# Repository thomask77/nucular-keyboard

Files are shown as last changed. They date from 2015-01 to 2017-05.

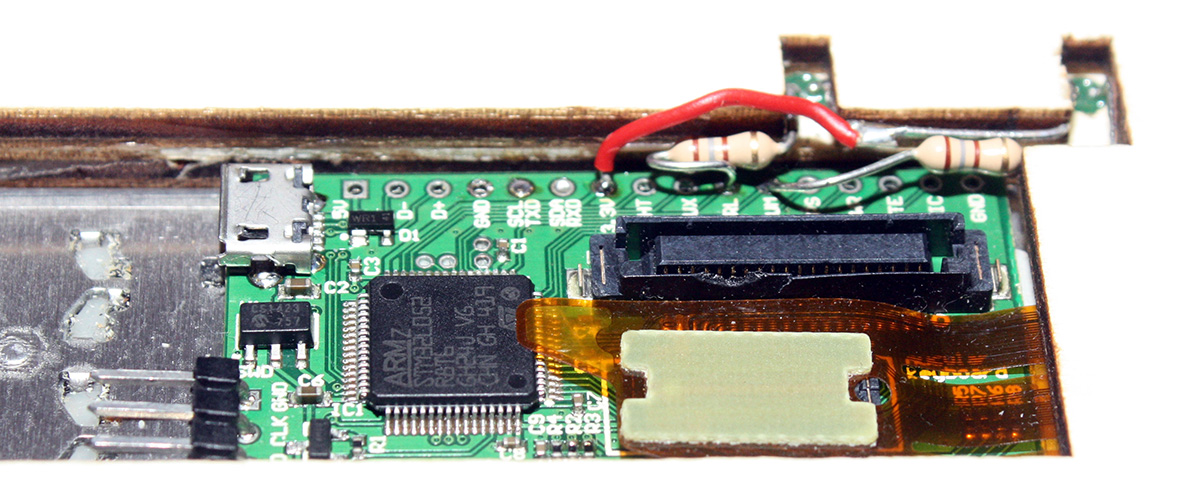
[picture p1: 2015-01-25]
Docs/IMG_5007.JPG

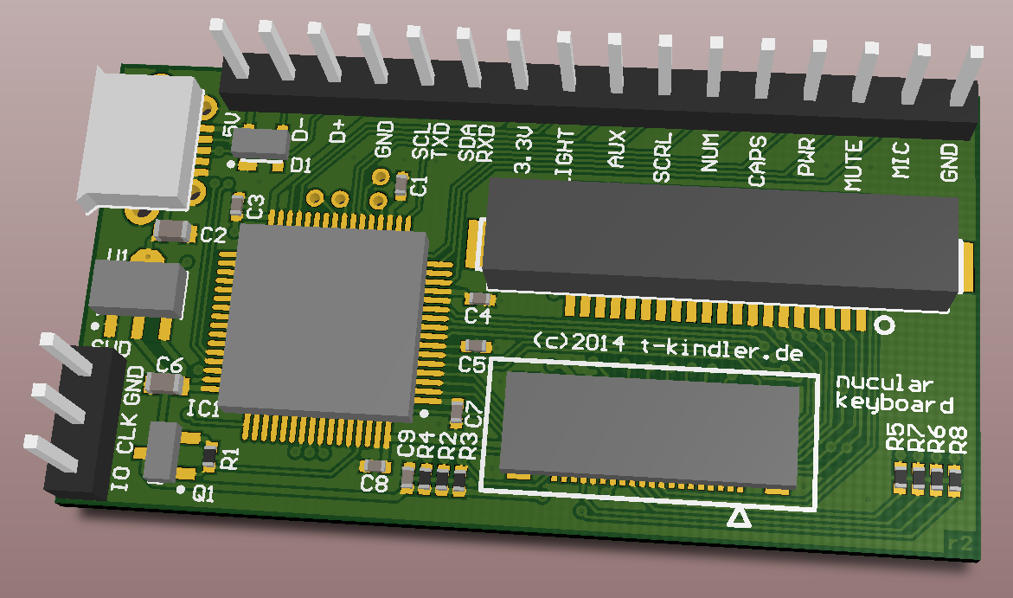
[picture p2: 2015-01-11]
Docs/nucular-keyboard.png

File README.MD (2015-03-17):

Toolchain
=========
  * gcc-arm-embedded toolchain >= 4.9-2014-q4
    * https://launchpad.net/gcc-arm-embedded

  * Other tools (use cygwin for windows)
    * python2
    * make

  * Initial flash programming
    * STM32 ST-LINK utility (windows)
    * https://github.com/texane/stlink (linux)

  * Flash programming with DFU bootloader
    * STM32 DfuSe utility (windows)
    * Openmoko dfu-util (linux)

Building
========
```bash
make boot    # Build USB DFU bootloader
make all     # Build actual keyboard application
```

Initial flash programming
=========================
Unfortunately, the STM32L052 does not have a built-in USB bootloader. So the
initial programming has to be done using a SWD adapter. A cheap STM32 discovery
board will do fine.

Windows
-------
Use the ST-LINK utility to flash `obj_boot/f00b00t.hex` and
`obj_app/nucular_kb.hex`.
   
Hint: You can also copy the ST-LINK utility to Tools/st-link and use `make`
to do the flashing:

```bash
make boot_flash
make flash
```

Linux
-----
Use Texane's stlink utility to do the flashing:

```bash
sudo st-flash --reset write obj_boot/f00b00t.bin 0x08000000
sudo st-flash --reset write obj_app/drquad.bin 0x08010000
```

Hint: Read the st-flash documentation and install udev rules
to flash without root privileges.

Flash programming with DFU bootloader
=====================================
After the USB DFU bootloader has been flashed, the application can be updated
without any external tools. Press FN+POWER on your keyboard to enter the DFU-
bootloader mode.

Windows
-------
Use ST's DfuSe Application to flash `obj_app/nucular_kb.dfu`

Linux
-----
Use Openmoko's dfu-util to flash the application:

```bash
sudo dfu-util -D obj_app/nucular_kb.dfu
```

printf()-Debugging
==================
The application uses a generic HID endpoint to print debug messages. This
endpoint is fully compatible with PJRC's [hid_listen] 
(https://www.pjrc.com/teensy/hid_listen.html) program.

The program (source and binaries) is included in the Tools directory.

Eclipse settings
================
  * Download and configure Eclipse Luna:
    * Help -> Install new Software -> Add
      * Name: `http://pydev.org/updates`
      * Location: `http://pydev.org/updates`
    * Install the following plugins:
      * Programming Languages
        * C/C++ Development Tools
      * Mobile and Device Development
        * C/C++ GCC Cross Compiler Support
        * C/C++ GDB Hardware Debugging
     * PyDev
        * PyDev for Eclipse
      * Collaboration
        * Eclipse Git Team Provider

  * Window -> Preferences
    * C/C++
      * Build -> Console -> Limit console output: `5000`
      * Editor -> Scalability -> .. number of lines: `50000`
      * Editor -> Folding -> Enable folding of preprocessor branches
      * Code Style -> Formatter -> Import: `Docs/Codestyle.xml`
      * Code Analysis -> Uncheck all options
    * General -> Editors -> Text Editors -> Spelling -> Disable spell checking

Import Project
--------------
  * File -> New -> Makefile Project with Existing Code
    -> Toolchain for Indexer Settigns: Cross GCC

  * Project -> Uncheck "Build Automatically" 
  
  * Project -> Properties -> C/C++ General
    * Preprocessor Include Paths, Macros, etc. -> Providers
      * CDT GCC Build Output Parser: `arm-none-eabi-gcc`
      * CDT Cross GCC Built-in Compiler Settings: `arm-none-eabi-gcc -E -P -v -dD "${INPUTS}"`

  * Make Target Window, Right Click -> New...
    * Target-name: `all -j8`
    * Target-name: `clean`

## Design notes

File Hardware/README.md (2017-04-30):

**KICAD BRANCH -- WORK IN PROGRESS**

**EXPECT FREQUENT REBASES**

# Hardware

# Software

  * KiCad nightly
  * FreeCAD v0.17_pre

# Credits
  * 3D Models for AA01B-S040VA1 and T60 Keyboard by Cong Nguyen, Licensed under
    [CC-BY](http://creativecommons.org/licenses/by/4.0/) License:
    * https://grabcad.com/library/aa01b-s040va1-model-1
    * https://grabcad.com/library/thinkpad-t60-keyboard-with-trackpoint-1

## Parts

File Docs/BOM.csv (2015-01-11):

Comment | Footprint | Quantity | Designator
100n | CAPC0402N | 7 | C1, C3, C4, C5, C7, C8, C9
10u | CAPC0603N | 2 | C2, C6
PRTR5V0U2X | SOT143B | 1 | D1
STM32L052 | TSQFP50P1200X1200X160-64N | 1 | IC1
JAE-KX14-KxD | JAE-KX14-K2D | 1 | J1
JAE-AA01B-S040VA1 | JAE-AA01B-S040VA1 | 1 | J2
HEADER 1x16 | HEADER 1x16 2.54MM | 1 | P1
IRLML6402 | SOT23_N | 1 | Q1
4k7 | RESC0402N | 4 | R1, R2, R3, R4
100R | RESC0402N | 4 | R5, R6, R7, R8
HEADER 1x3 | HEADER 1x3 2.54MM | 1 | SWD
MCP1700T-3302E/MB | SOT-89-MB3_N | 1 | U1
USB | USB_MICRO_FCI | 1 | USB1

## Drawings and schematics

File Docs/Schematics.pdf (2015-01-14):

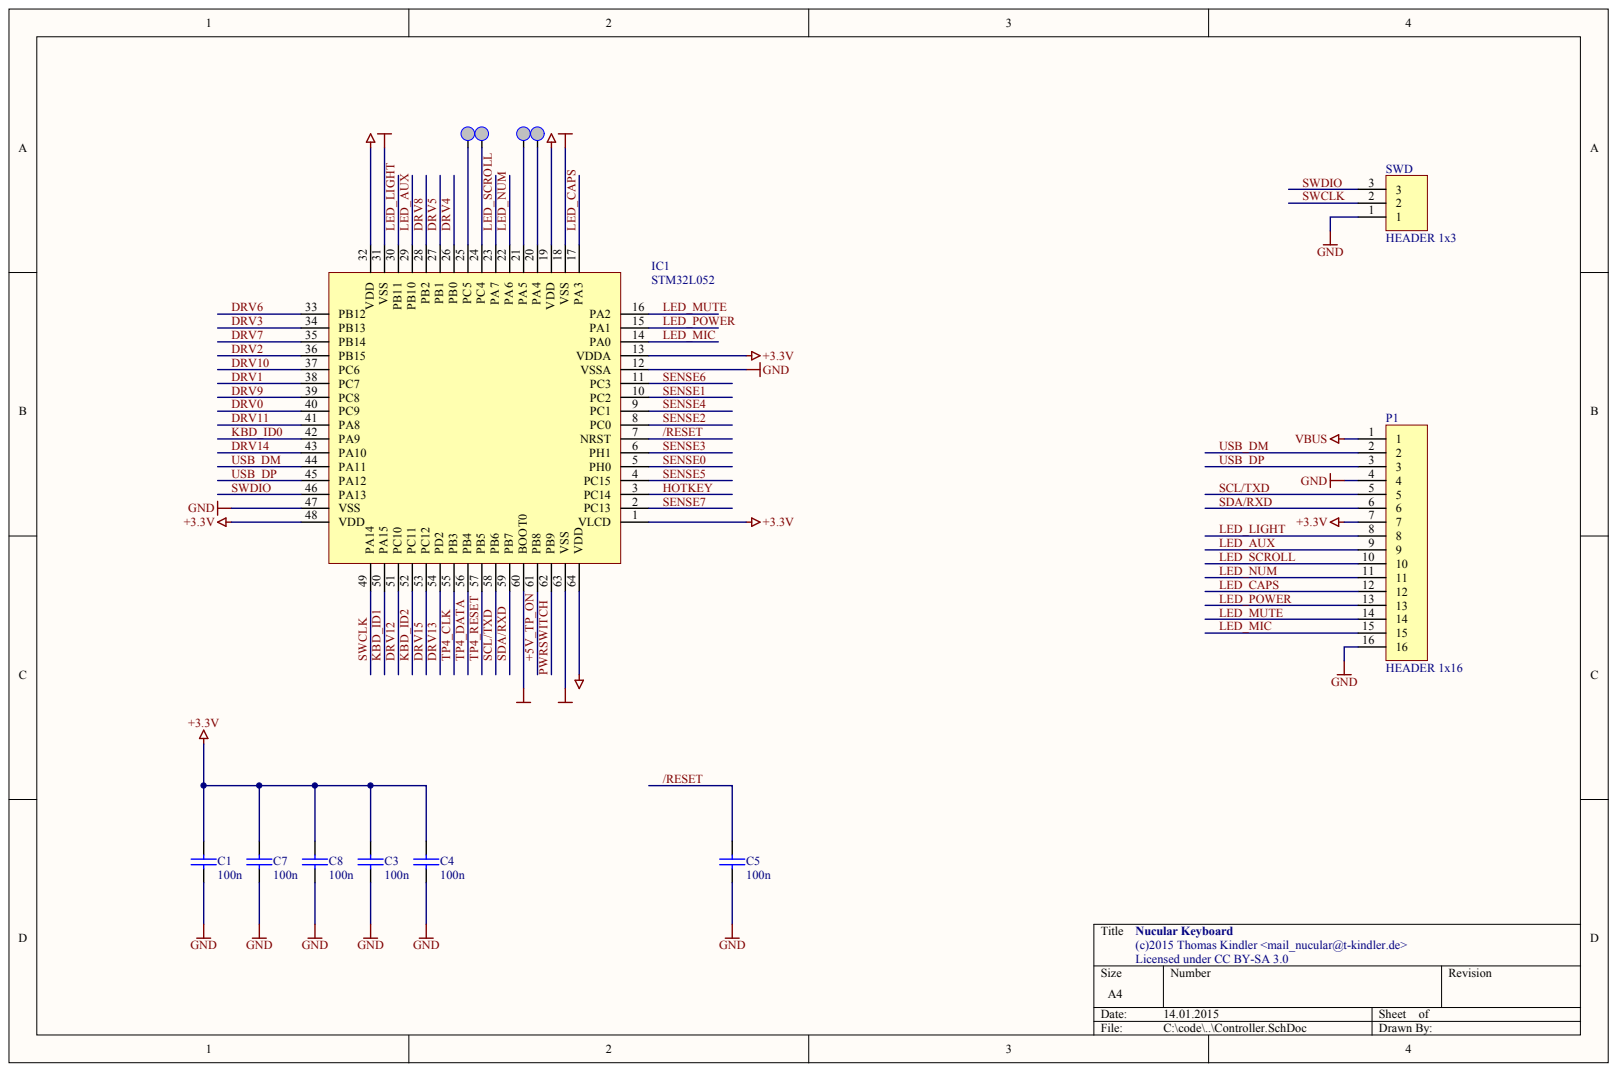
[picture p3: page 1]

PA3 17 VSS 18 VDD 19 PA4 20 PA5 21 PA6 22 PA7 23 PC4 24 PC5 25 PB0 26 PB1 27 PB2 28 PB10 29 PB11 30 VSS 31 VDD 32

SCL/TXD SDA/RXD

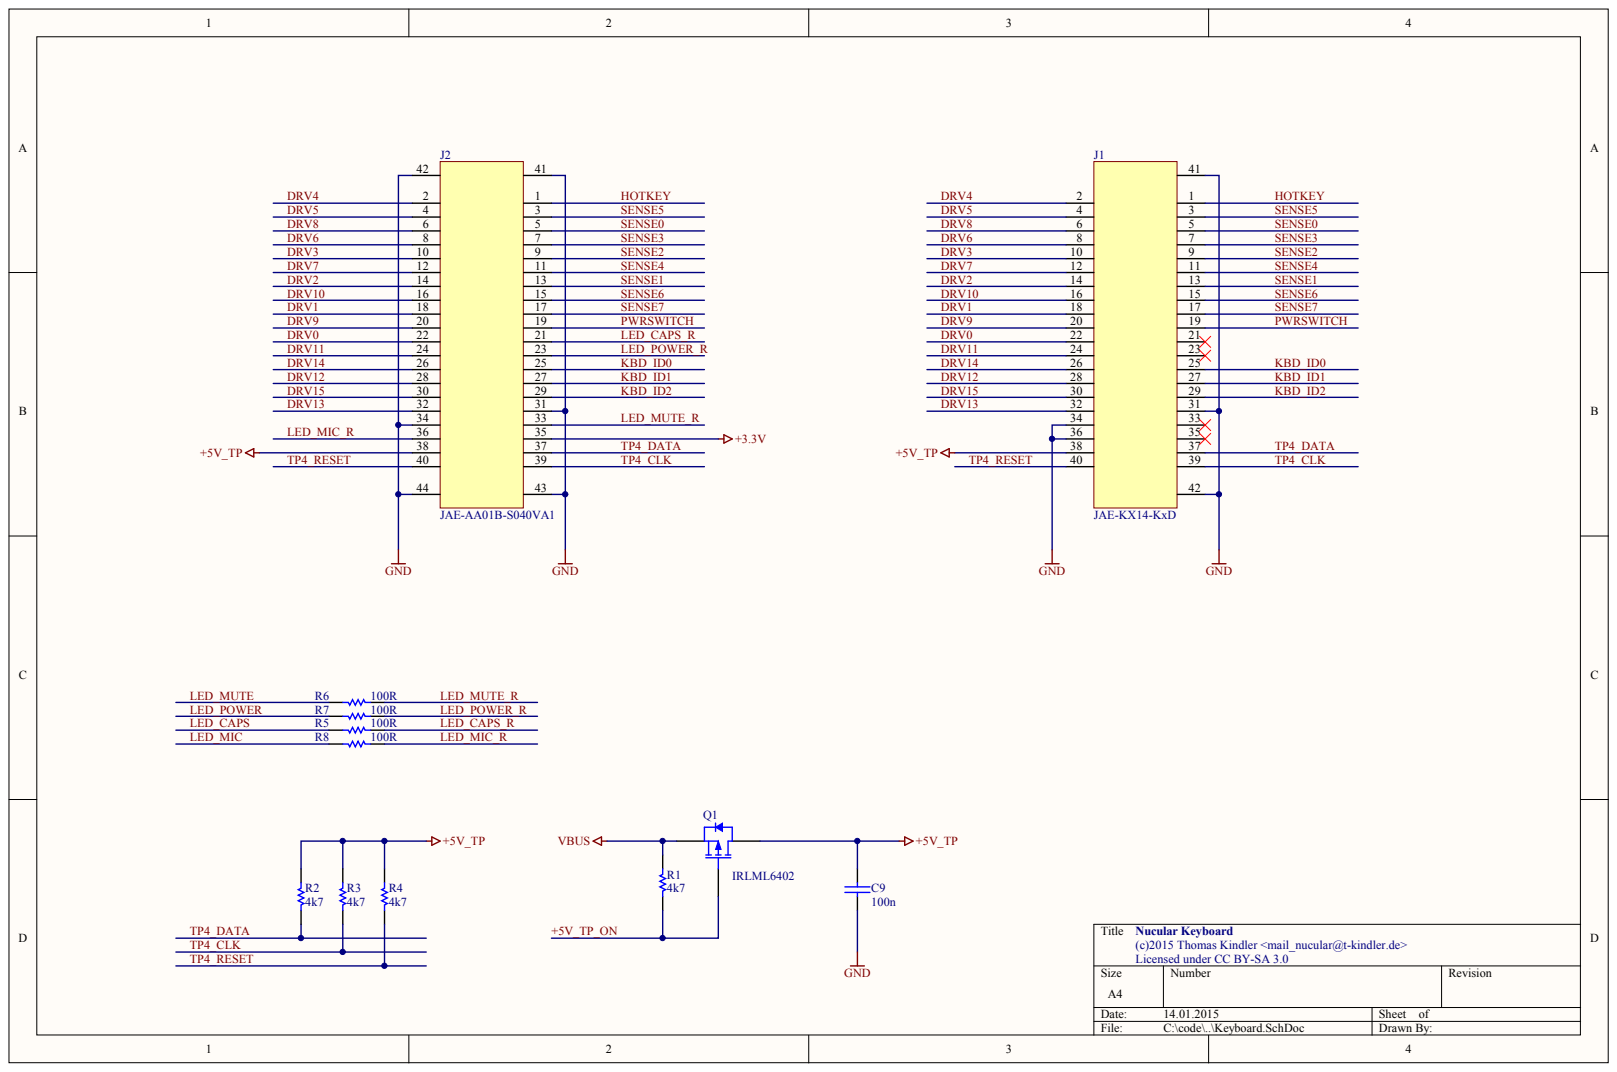
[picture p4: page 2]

2 4 6 8 10 12 14 16 18 20 22 24 26 28 30 32 34 | 1
3 | SENSE5
5 | SENSE0
7 | SENSE3
9 | SENSE2
11 | SENSE4
13 | SENSE1
15 | SENSE6
17 | SENSE7
19 | PWRSWITCH
21 | LED_CAPS_R
23 | LED_POWER_R
25 | KBD_ID0
27 | KBD_ID1
29 | KBD_ID2
31 | LED_MUTE_R
33

Nucular Keyboard
(c)2015 Thomas Kindler <mail_nucular@t-kindler.de>
Licensed under CC BY-SA 3.0

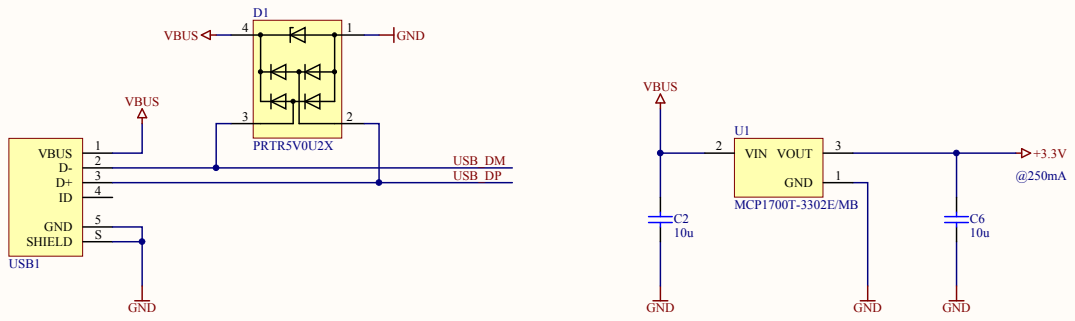
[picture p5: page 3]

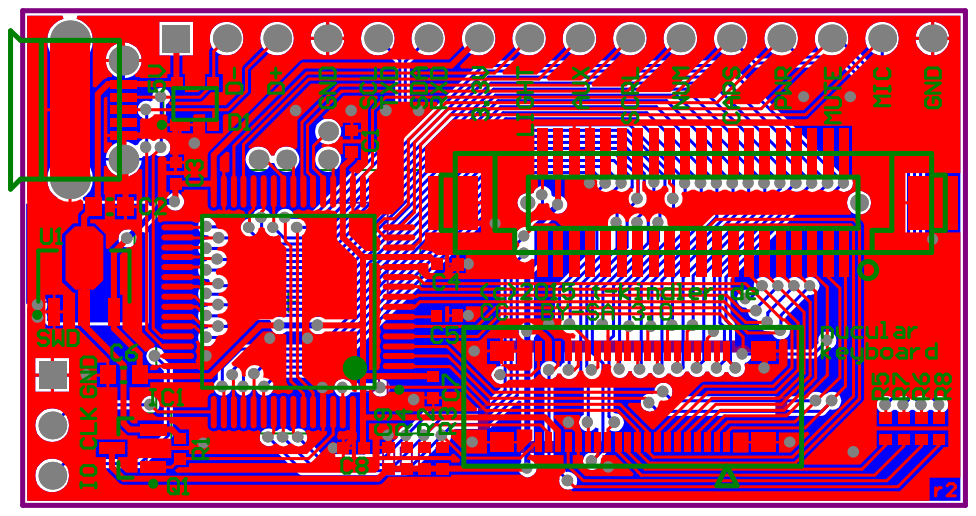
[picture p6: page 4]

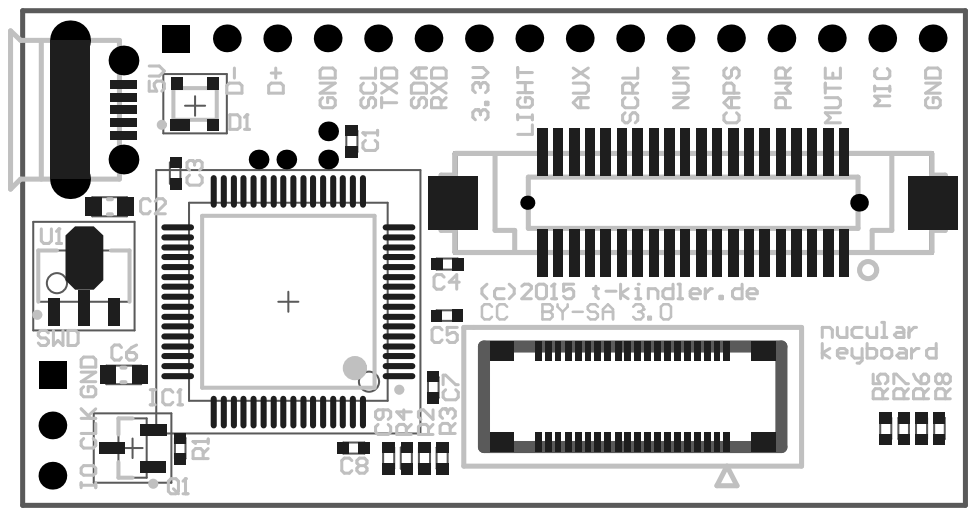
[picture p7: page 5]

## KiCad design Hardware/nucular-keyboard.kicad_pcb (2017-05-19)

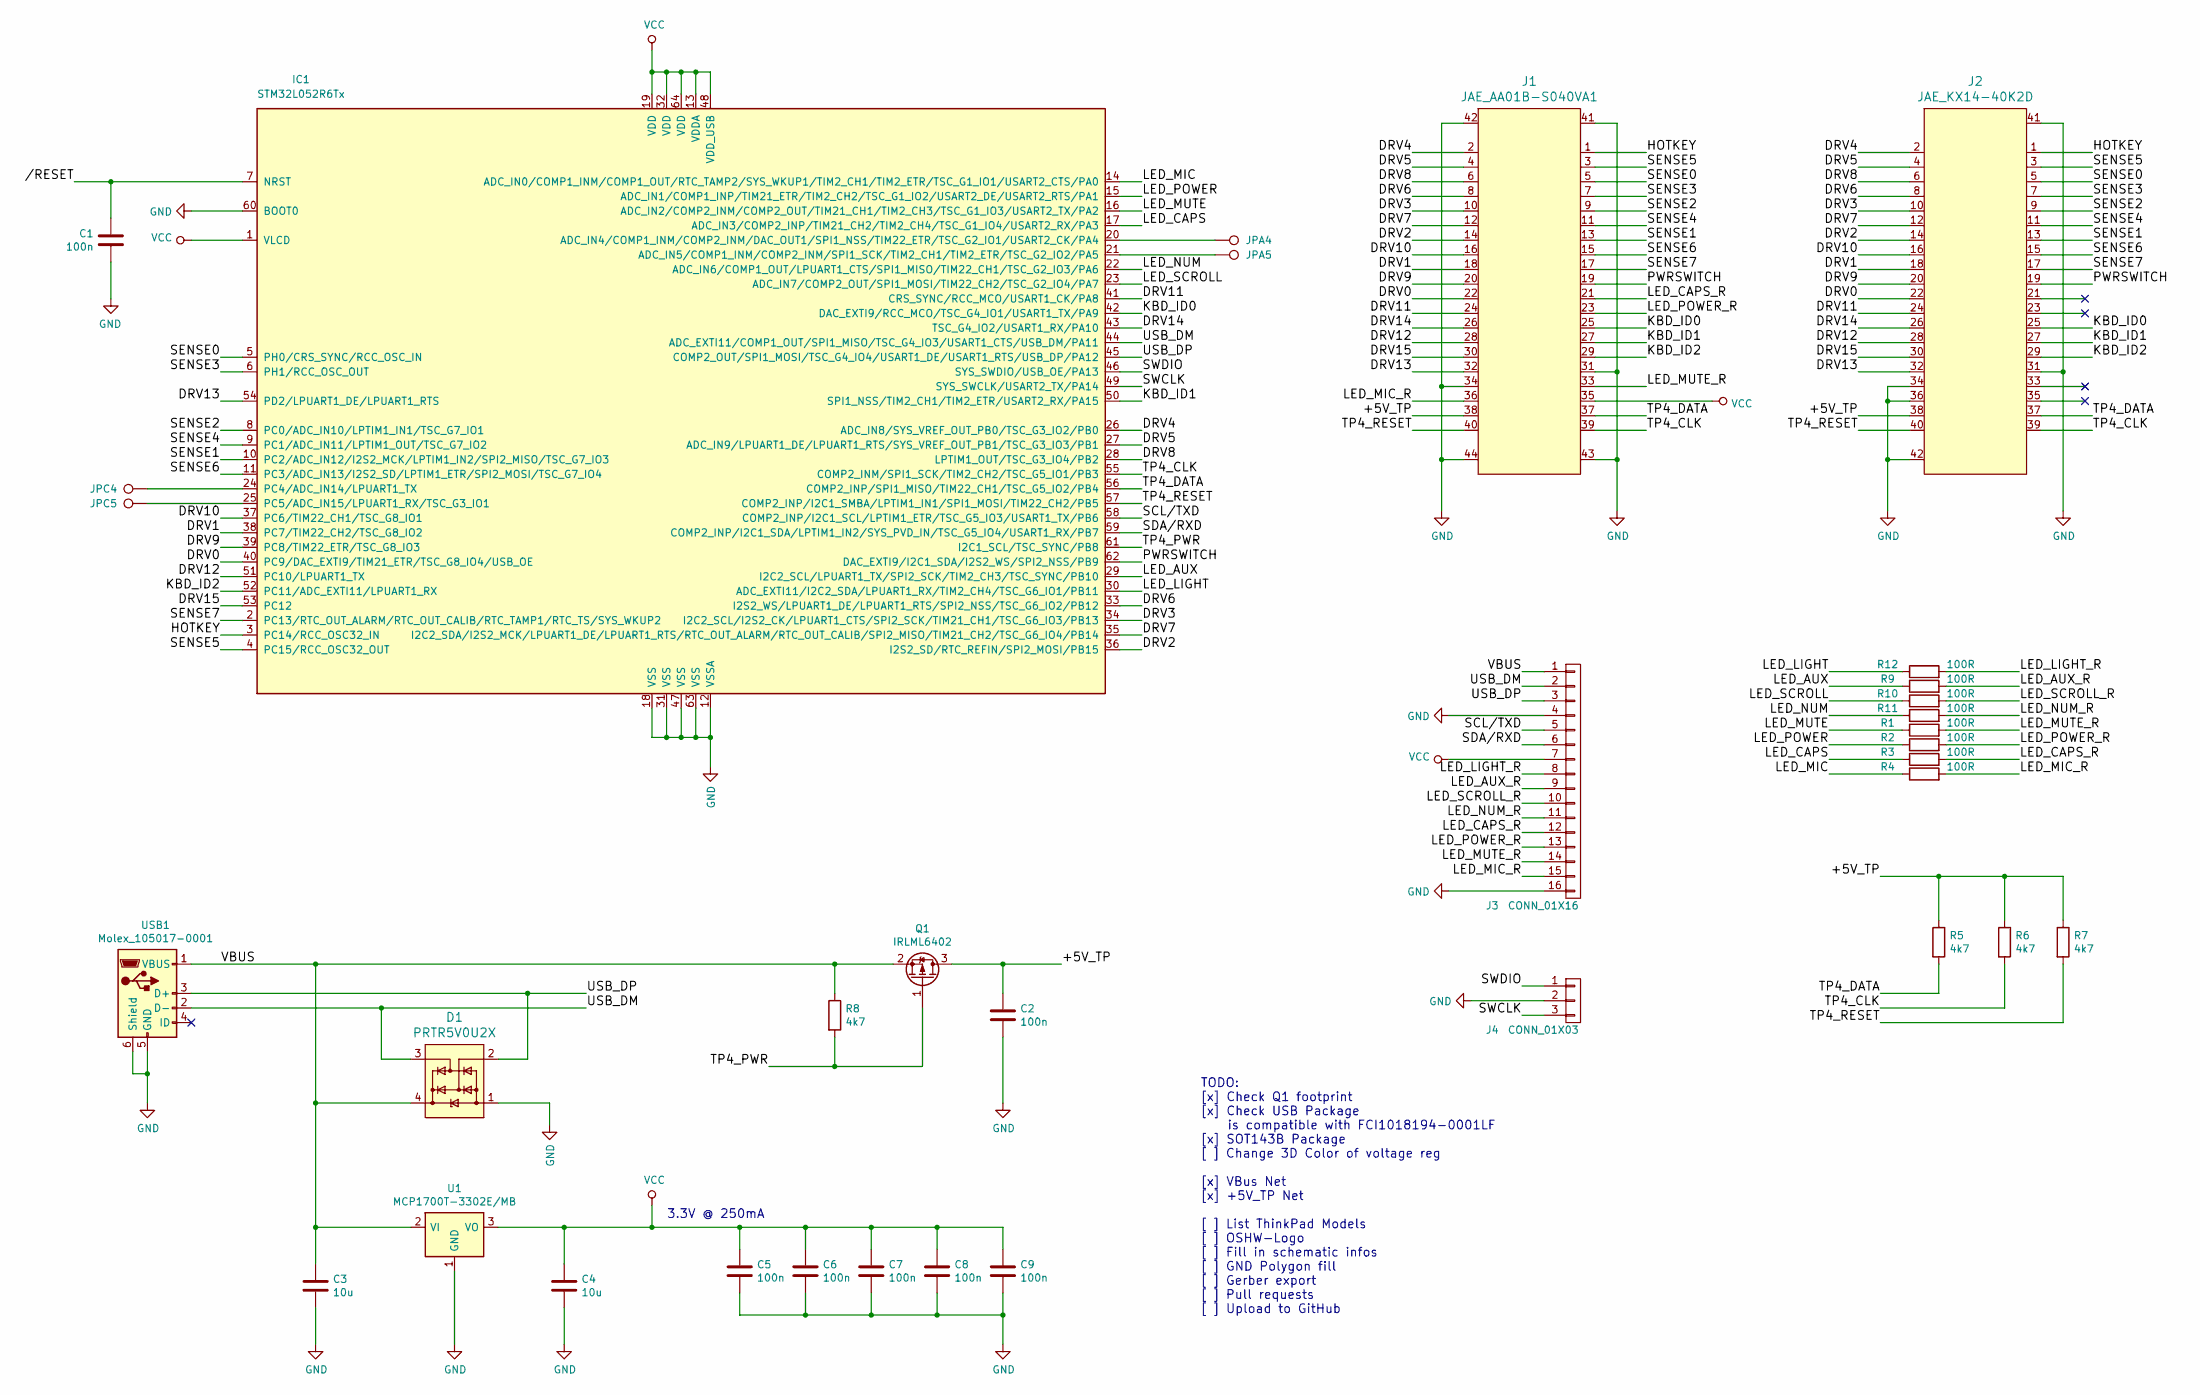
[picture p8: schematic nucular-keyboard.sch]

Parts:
C1, C2, C5, C6, C7, C8, C9: 100n; C_0402
C3, C4: 10u; C_0603
D1: PRTR5V0U2X; SOT143B
IC1: STM32L052R6Tx; LQFP-64_10x10mm_Pitch0.5mm
J1: JAE_AA01B-S040VA1
J2: JAE_KX14-40K2D
J3: CONN_01X16; Pin_Header_Straight_1x16_Pitch2.54mm
J4: CONN_01X03; Pin_Header_Straight_1x03_Pitch2.54mm
JPA4, JPA5: TEST_1P; SolderWirePad_single_0-8mmDrill
JPC4, JPC5: TEST_1P; SolderWirePad_single_0-8mmDrill
Q1: IRLML6402; SOT-23
R1, R2, R3, R4, R9, R10, R11, R12: 100R; R_0402
R5, R6, R7, R8: 4k7; R_0402
U1: MCP1700T-3302E/MB; SOT89-3
USB1: Molex_105017-0001; Molex_105017-0001_USB-Micro-B

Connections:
/+5V_TP: C2.1, J1.38, J2.38, Q1.3 (D), R5.1, R6.1, R7.1
//RESET: C1.1, IC1.7 (NRST)
/DRV0: IC1.40 (PC9/DAC_EXTI9/TIM21_ETR/TSC_G8_IO4/USB_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), J1.22, J2.22
/DRV1: IC1.38 (PC7/TIM22_CH2/TSC_G8_IO2), J1.18, J2.18
/DRV2: IC1.36 (I2S2_SD/RTC_REFIN/SPI2_MOSI/PB15), J1.14, J2.14
/DRV3: IC1.34 (I2C2_SCL/I2S2_CK/LPUART1_CTS/SPI2_SCK/T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), J1.10, J2.10
/DRV4: IC1.26 (ADC_IN8/SYS_VREF_OUT_PB0/TSC_G3_IO2/PB0), J1.2, J2.2
/DRV5: IC1.27 (ADC_IN9/LPUART1_DE/LPUART1_RTS/SYS_VREF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), J1.4, J2.4
/DRV6: IC1.33 (I2S2_WS/LPUART1_DE/LPUART1_RTS/SPI2_NSS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), J1.8, J2.8
/DRV7: IC1.35 (I2C2_SDA/I2S2_MCK/LPUART1_DE/LPUART1_RT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), J1.12, J2.12
/DRV8: IC1.28 (LPTIM1_OUT/TSC_G3_IO4/PB2), J1.6, J2.6
/DRV9: IC1.39 (PC8/TIM22_ETR/TSC_G8_IO3), J1.20, J2.20
/DRV10: IC1.37 (PC6/TIM22_CH1/TSC_G8_IO1), J1.16, J2.16
/DRV11: IC1.41 (CRS_SYNC/RCC_MCO/USART1_CK/PA8), J1.24, J2.24
/DRV12: IC1.51 (PC10/LPUART1_TX), J1.28, J2.28
/DRV13: IC1.54 (PD2/LPUART1_DE/LPUART1_RTS), J1.32, J2.32
/DRV14: IC1.43 (TSC_G4_IO2/USART1_RX/PA10), J1.26, J2.26
/DRV15: IC1.53 (PC12), J1.30, J2.30
/HOTKEY: IC1.3 (PC14/RCC_OSC32_IN), J1.1, J2.1
/KBD_ID0: IC1.42 (DAC_EXTI9/RCC_MCO/TSC_G4_IO1/USART1_TX/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), J1.25, J2.25
/KBD_ID1: IC1.50 (SPI1_NSS/TIM2_CH1/TIM2_ETR/USART2_RX/PA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), J1.27, J2.27
/KBD_ID2: IC1.52 (PC11/ADC_EXTI11/LPUART1_RX), J1.29, J2.29
/LED_AUX: IC1.29 (I2C2_SCL/LPUART1_TX/SPI2_SCK/TIM2_CH3/T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), R9.1
/LED_AUX_R: J3.9, R9.2
/LED_CAPS: IC1.17 (ADC_IN3/COMP2_INP/TIM21_CH2/TIM2_CH4/TS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), R3.1
/LED_CAPS_R: J1.21, J3.12, R3.2
/LED_LIGHT: IC1.30 (ADC_EXTI11/I2C2_SDA/LPUART1_RX/TIM2_CH4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), R12.1
/LED_LIGHT_R: J3.8, R12.2
/LED_MIC: IC1.14 (ADC_IN0/COMP1_INM/COMP1_OUT/RTC_TAMP2/S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), R4.1
/LED_MIC_R: J1.36, J3.15, R4.2
/LED_MUTE: IC1.16 (ADC_IN2/COMP2_INM/COMP2_OUT/TIM21_CH1/T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), R1.1
/LED_MUTE_R: J1.33, J3.14, R1.2
/LED_NUM: IC1.22 (ADC_IN6/COMP1_OUT/LPUART1_CTS/SPI1_MISO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), R11.1
/LED_NUM_R: J3.11, R11.2
/LED_POWER: IC1.15 (ADC_IN1/COMP1_INP/TIM21_ETR/TIM2_CH2/TS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), R2.1
/LED_POWER_R: J1.23, J3.13, R2.2
/LED_SCROLL: IC1.23 (ADC_IN7/COMP2_OUT/SPI1_MOSI/TIM22_CH2/T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), R10.1
/LED_SCROLL_R: J3.10, R10.2
/PWRSWITCH: IC1.62 (DAC_EXTI9/I2C1_SDA/I2S2_WS/SPI2_NSS/PB9), J1.19, J2.19
/SCL/TXD: IC1.58 (COMP2_INP/I2C1_SCL/LPTIM1_ETR/TSC_G5_IO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), J3.5
/SDA/RXD: IC1.59 (COMP2_INP/I2C1_SDA/LPTIM1_IN2/SYS_PVD_I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), J3.6
/SENSE0: IC1.5 (PH0/CRS_SYNC/RCC_OSC_IN), J1.5, J2.5
/SENSE1: IC1.10 (PC2/ADC_IN12/I2S2_MCK/LPTIM1_IN2/SPI2_M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), J1.13, J2.13
/SENSE2: IC1.8 (PC0/ADC_IN10/LPTIM1_IN1/TSC_G7_IO1), J1.9, J2.9
/SENSE3: IC1.6 (PH1/RCC_OSC_OUT), J1.7, J2.7
/SENSE4: IC1.9 (PC1/ADC_IN11/LPTIM1_OUT/TSC_G7_IO2), J1.11, J2.11
/SENSE5: IC1.4 (PC15/RCC_OSC32_OUT), J1.3, J2.3
/SENSE6: IC1.11 (PC3/ADC_IN13/I2S2_SD/LPTIM1_ETR/SPI2_MO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), J1.15, J2.15
/SENSE7: IC1.2 (PC13/RTC_OUT_ALARM/RTC_OUT_CALIB/RTC_TA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), J1.17, J2.17
/SWCLK: IC1.49 (SYS_SWCLK/USART2_TX/PA14), J4.3
/SWDIO: IC1.46 (SYS_SWDIO/USB_OE/PA13), J4.1
/TP4_CLK: IC1.55 (COMP2_INM/SPI1_SCK/TIM2_CH2/TSC_G5_IO1/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), J1.39, J2.39, R6.2
/TP4_DATA: IC1.56 (COMP2_INP/SPI1_MISO/TIM22_CH1/TSC_G5_IO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), J1.37, J2.37, R5.2
/TP4_PWR: IC1.61 (I2C1_SCL/TSC_SYNC/PB8), Q1.1 (G), R8.2
/TP4_RESET: IC1.57 (COMP2_INP/I2C1_SMBA/LPTIM1_IN1/SPI1_MOS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), J1.40, J2.40, R7.2
/USB_DM: D1.3 (DM), IC1.44 (ADC_EXTI11/COMP1_OUT/SPI1_MISO/TSC_G4_I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), J3.2, USB1.2 (D-)
/USB_DP: D1.2 (DP), IC1.45 (COMP2_OUT/SPI1_MOSI/TSC_G4_IO4/USART1_D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), J3.3, USB1.3 (D+)
/VBUS: C3.1, D1.4 (VBUS), J3.1, Q1.2 (S), R8.1, U1.2 (VI), USB1.1 (VBUS)
GND: C1.2, C2.2, C3.2, C4.2, C5.2, C6.2, C7.2, C8.2, C9.2, D1.1 (GND), IC1.12 (VSSA), IC1.18 (VSS), IC1.31 (VSS), IC1.47 (VSS), IC1.60 (BOOT0), IC1.63 (VSS), J1.31, J1.34, J1.41, J1.42, J1.43, J1.44, J2.31, J2.34, J2.36, J2.41, J2.42, J3.4, J3.16, J4.2, U1.1 (GND), USB1.5 (GND), USB1.6 (Shield)
unnamed: IC1.20 (ADC_IN4/COMP1_INM/COMP2_INM/DAC_OUT1/SP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), JPA4.1
unnamed: IC1.21 (ADC_IN5/COMP1_INM/COMP2_INM/SPI1_SCK/TI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), JPA5.1
unnamed: IC1.24 (PC4/ADC_IN14/LPUART1_TX), JPC4.1
unnamed: IC1.25 (PC5/ADC_IN15/LPUART1_RX/TSC_G3_IO1), JPC5.1
VCC: C4.1, C5.1, C6.1, C7.1, C8.1, C9.1, IC1.1 (VLCD), IC1.13 (VDDA), IC1.19 (VDD), IC1.32 (VDD), IC1.48 (VDD_USB), IC1.64 (VDD), J1.35, J3.7, U1.3 (VO)

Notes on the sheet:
3.3V @ 250mA
TODO: [x] Check Q1 footprint [x] Check USB Package is compatible with FCI1018194-0001LF [x] SOT143B Package [ ] Change 3D Color of voltage reg [x] VBus Net [x] +5V_TP Net [ ] List ThinkPad Models [ ] OSHW-Logo [ ] Fill in schematic infos [ ] GND Polygon fill [ ] Gerber export [ ] Pull requests [ ] 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

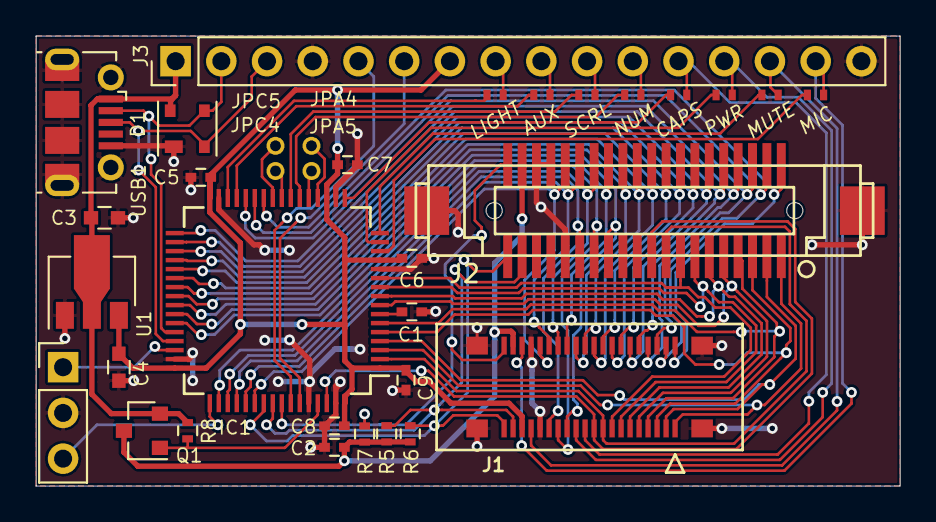
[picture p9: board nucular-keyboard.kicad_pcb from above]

Board: 2 copper layers, 48.0 x 25.0 mm, 34 parts (0 on the bottom side), 64 nets.

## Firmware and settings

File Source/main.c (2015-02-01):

/**
 * Nucular Keyboard - ThinkPad USB Adapter
 * Copyright (C)2015 Thomas Kindler <mail_nucular@t-kindler.de>
 *
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
 * You should have received a copy of the GNU General Public License
 * along with this program.  If not, see <http://www.gnu.org/licenses/>.
 */
#include "hid_debug.h"
#include "kb_driver.h"
#include "keyboard.h"
#include "ps2_host.h"
#include "trackpoint.h"
#include "ustime.h"
#include "ansi.h"
#include "usbd_desc.h"
#include "usbd_hid.h"
#include "stm32l0xx.h"


static IWDG_HandleTypeDef hiwdg;
USBD_HandleTypeDef hUsbDeviceFS;
extern PCD_HandleTypeDef hpcd_USB_FS;


void USB_IRQHandler(void)
{
    HAL_NVIC_ClearPendingIRQ(USB_IRQn);
    HAL_PCD_IRQHandler(&hpcd_USB_FS);
}


void SysTick_Handler(void)
{
    HAL_IncTick();
    HAL_SYSTICK_IRQHandler();
}


void SystemClock_Config(void)
{
    RCC_CRSInitTypeDef RCC_CRSInitStruct;
    RCC_ClkInitTypeDef RCC_ClkInitStruct;
    RCC_PeriphCLKInitTypeDef PeriphClkInit;
    RCC_OscInitTypeDef RCC_OscInitStruct;

    __PWR_CLK_ENABLE();

    __HAL_PWR_VOLTAGESCALING_CONFIG(PWR_REGULATOR_VOLTAGE_SCALE1);

    RCC_OscInitStruct.OscillatorType = RCC_OSCILLATORTYPE_HSI | RCC_OSCILLATORTYPE_LSI | RCC_OSCILLATORTYPE_HSI48;
    RCC_OscInitStruct.HSIState = RCC_HSI_ON;
    RCC_OscInitStruct.HSICalibrationValue = 16;
    RCC_OscInitStruct.LSIState = RCC_LSI_ON;
    RCC_OscInitStruct.HSI48State = RCC_HSI48_ON;
    RCC_OscInitStruct.PLL.PLLState = RCC_PLL_ON;
    RCC_OscInitStruct.PLL.PLLSource = RCC_PLLSOURCE_HSI;
    RCC_OscInitStruct.PLL.PLLMUL = RCC_PLLMUL_4;
    RCC_OscInitStruct.PLL.PLLDIV = RCC_PLLDIV_2;
    HAL_RCC_OscConfig(&RCC_OscInitStruct);

    RCC_ClkInitStruct.ClockType = RCC_CLOCKTYPE_SYSCLK;
    RCC_ClkInitStruct.SYSCLKSource = RCC_SYSCLKSOURCE_PLLCLK;
    RCC_ClkInitStruct.AHBCLKDivider = RCC_SYSCLK_DIV1;
    RCC_ClkInitStruct.APB1CLKDivider = RCC_HCLK_DIV1;
    RCC_ClkInitStruct.APB2CLKDivider = RCC_HCLK_DIV1;
    HAL_RCC_ClockConfig(&RCC_ClkInitStruct, FLASH_LATENCY_1);

    PeriphClkInit.PeriphClockSelection = RCC_PERIPHCLK_USART1 | RCC_PERIPHCLK_USB;
    PeriphClkInit.Usart1ClockSelection = RCC_USART1CLKSOURCE_PCLK2;
    PeriphClkInit.UsbClockSelection = RCC_USBCLKSOURCE_HSI48;
    HAL_RCCEx_PeriphCLKConfig(&PeriphClkInit);

    __SYSCFG_CLK_ENABLE();

    __CRS_CLK_ENABLE();

    RCC_CRSInitStruct.Prescaler = RCC_CRS_SYNC_DIV1;
    RCC_CRSInitStruct.Source = RCC_CRS_SYNC_SOURCE_USB;
    RCC_CRSInitStruct.Polarity = RCC_CRS_SYNC_POLARITY_RISING;
    RCC_CRSInitStruct.ReloadValue = __HAL_RCC_CRS_CALCULATE_RELOADVALUE(48000000, 1000);
    RCC_CRSInitStruct.ErrorLimitValue = 34;
    RCC_CRSInitStruct.HSI48CalibrationValue = 32;
    HAL_RCCEx_CRSConfig(&RCC_CRSInitStruct);
}


static void MX_IWDG_Init(void)
{
    hiwdg.Instance = IWDG;
    hiwdg.Init.Prescaler = IWDG_PRESCALER_4;
    hiwdg.Init.Reload = 50;
    HAL_IWDG_Init(&hiwdg);
}


void MX_GPIO_Init(void)
{
    /* GPIO Ports Clock Enable */
    __GPIOA_CLK_ENABLE();
    __GPIOB_CLK_ENABLE();
    __GPIOC_CLK_ENABLE();
    __GPIOD_CLK_ENABLE();
}


void MX_USB_DEVICE_Init(void)
{
    USBD_Init(&hUsbDeviceFS, &FS_Desc, DEVICE_FS);
    USBD_RegisterClass(&hUsbDeviceFS, &USBD_HID);
    USBD_Start(&hUsbDeviceFS);
}


void assert_failed(uint8_t* file, uint32_t line)
{
    printf("assert failed: %s:%lu\n", file, line);
}


void handle_out_requests(void)
{
    USBD_HID_HandleTypeDef *hhid = hUsbDeviceFS.pClassData;

    if (!hhid->ep0_out_req_ready)
        return;

    uint8_t report_type = hhid->ep0_out_req.wValue >> 8;
    uint8_t report_id = hhid->ep0_out_req.wValue & 0xff;

    switch (hhid->ep0_out_req.wIndex) {
    case 0:
        if (report_type == 2 && report_id == 0)
            kb_set_leds((struct kb_out_report *)hhid->ep0_out_buf);
        break;

    case 2:
        if (report_type == 3 && report_id == 0x80)
            enter_bootloader();
        break;
    }

    hhid->ep0_out_req_ready = 0;
}


int main(void)
{
    SCB->VTOR = 0x8004000;  // Relocate IRQ table

    HAL_Init();
    SystemClock_Config();
    HAL_NVIC_SetPriority(SysTick_IRQn, 0, 0);

    MX_GPIO_Init();
    // MX_IWDG_Init();
    MX_USB_DEVICE_Init();

    // PA4  Debug output
    // PA5  Debug output
    //
    HAL_GPIO_Init(GPIOA, &(GPIO_InitTypeDef) {
        .Pin   = GPIO_PIN_4 | GPIO_PIN_5,
        .Mode  = GPIO_MODE_OUTPUT_PP,
        .Pull  = GPIO_PULLUP,
        .Speed = GPIO_SPEED_LOW
    } );

    init_us_timer();

    printf("Initializing keyboard interface..\n");
    kb_init();

    printf("Initializing TrackPoint interface..\n");
    tp_init();

    static struct tp_mouse_report     mr_old;
    static struct kb_in_report        kr_old;
    static struct kb_sysctrl_report   sr_old;
    static struct kb_consumer_report  cr_old;

    for (;;) {
        kb_update();
        tp_update();

        // Send keyboard reports on state change only
        //
        if (memcmp(&kb_in_report, &kr_old, sizeof(kb_in_report))) {
            if (USBD_HID_SendReport(&hUsbDeviceFS, HID_KEYBOARD_EPIN_ADDR, &kb_in_report, sizeof(kb_in_report)) == USBD_OK)
                kr_old = kb_in_report;
        }

        if (memcmp(&kb_sysctrl_report, &sr_old, sizeof(kb_sysctrl_report))) {
            if (USBD_HID_SendReport(&hUsbDeviceFS, HID_EXTRA_EPIN_ADDR, &kb_sysctrl_report, sizeof(kb_sysctrl_report)) == USBD_OK)
                sr_old = kb_sysctrl_report;
        }

        if (memcmp(&kb_consumer_report, &cr_old, sizeof(kb_consumer_report))) {
            if (USBD_HID_SendReport(&hUsbDeviceFS, HID_EXTRA_EPIN_ADDR, &kb_consumer_report, sizeof(kb_consumer_report)) == USBD_OK)
                cr_old = kb_consumer_report;
        }

        // Send mouse reports while moving and on button change
        //
        if (tp_mouse_report.dx      || tp_mouse_report.dy   ||
            tp_mouse_report.dwheel  || tp_mouse_report.dpan ||
            tp_mouse_report.buttons != mr_old.buttons)
        {
            if (USBD_HID_SendReport(&hUsbDeviceFS, HID_MOUSE_EPIN_ADDR, &tp_mouse_report, sizeof(tp_mouse_report)) == USBD_OK) {
                tp_clear_mouse_report();
                mr_old = tp_mouse_report;
            }
        }

        hid_debug_flush();

        handle_out_requests();
    }
}

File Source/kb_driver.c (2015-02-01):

/**
 * Nucular Keyboard - Low-level keyboard driver
 * Copyright (C)2015 Thomas Kindler <mail_nucular@t-kindler.de>
 *
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
 * You should have received a copy of the GNU General Public License
 * along with this program.  If not, see <http://www.gnu.org/licenses/>.
 */
#include "kb_driver.h"
#include "ustime.h"
#include "util.h"
#include "gamma_tab.inc"
#include "stm32l0xx_hal.h"
#include <stdio.h>


// If you ever change the pinout, print this stuff out and tick it off with a pencil..
//
#define GPIOA_DRV_BITS      (GPIO_PIN_8  | GPIO_PIN_10)
#define GPIOB_DRV_BITS      (GPIO_PIN_0  | GPIO_PIN_1 | GPIO_PIN_2 | GPIO_PIN_12 | GPIO_PIN_13 | GPIO_PIN_14 | GPIO_PIN_15)
#define GPIOC_DRV_BITS      (GPIO_PIN_6  | GPIO_PIN_7 | GPIO_PIN_8 | GPIO_PIN_9  | GPIO_PIN_10 | GPIO_PIN_12)
#define GPIOD_DRV_BITS      (GPIO_PIN_2)

#define GPIOC_SENSE_BITS    (GPIO_PIN_0 | GPIO_PIN_1 | GPIO_PIN_2 | GPIO_PIN_3 | GPIO_PIN_13 | GPIO_PIN_15)
#define GPIOH_SENSE_BITS    (GPIO_PIN_0 | GPIO_PIN_1)

#define GPIOA_SPECIAL_BITS  (GPIO_PIN_9 | GPIO_PIN_15)
#define GPIOB_SPECIAL_BITS  (GPIO_PIN_9)
#define GPIOC_SPECIAL_BITS  (GPIO_PIN_11 | GPIO_PIN_14)

#define GPIOA_ALL_BITS      (GPIOA_DRV_BITS | GPIOA_SPECIAL_BITS)
#define GPIOB_ALL_BITS      (GPIOB_DRV_BITS | GPIOB_SPECIAL_BITS)
#define GPIOC_ALL_BITS      (GPIOC_DRV_BITS | GPIOC_SPECIAL_BITS | GPIOC_SENSE_BITS)
#define GPIOD_ALL_BITS      (GPIOD_DRV_BITS)
#define GPIOH_ALL_BITS      (GPIOH_SENSE_BITS)


static void discharge(void)
{
    // set all lines high
    //
    GPIOA->BSRR = GPIOA_DRV_BITS;
    GPIOB->BSRR = GPIOB_DRV_BITS;
    GPIOC->BSRR = (GPIOC_DRV_BITS | GPIOC_SENSE_BITS);
    GPIOD->BSRR = GPIOD_DRV_BITS;
    GPIOH->BSRR = GPIOH_SENSE_BITS;

    // use push/pull to boost the rising edge
    //
    GPIOA->OTYPER &= ~GPIOA_DRV_BITS;
    GPIOB->OTYPER &= ~GPIOB_DRV_BITS;
    GPIOC->OTYPER &= ~(GPIOC_DRV_BITS | GPIOC_SENSE_BITS);
    GPIOD->OTYPER &= ~GPIOD_DRV_BITS;
    GPIOH->OTYPER &= ~GPIOH_SENSE_BITS;

    // switch back to open-drain
    //
    GPIOA->OTYPER |= GPIOA_DRV_BITS;
    GPIOB->OTYPER |= GPIOB_DRV_BITS;
    GPIOC->OTYPER |= (GPIOC_DRV_BITS | GPIOC_SENSE_BITS);
    GPIOD->OTYPER |= GPIOD_DRV_BITS;
    GPIOH->OTYPER |= GPIOH_SENSE_BITS;
}


static void set_drv(int d)
{
    // set active line low
    //
    switch (d) {
    case  0: GPIOC->BRR = GPIO_PIN_9;   break;
    case  1: GPIOC->BRR = GPIO_PIN_7;   break;
    case  2: GPIOB->BRR = GPIO_PIN_15;  break;
    case  3: GPIOB->BRR = GPIO_PIN_13;  break;
    case  4: GPIOB->BRR = GPIO_PIN_0;   break;
    case  5: GPIOB->BRR = GPIO_PIN_1;   break;
    case  6: GPIOB->BRR = GPIO_PIN_12;  break;
    case  7: GPIOB->BRR = GPIO_PIN_14;  break;
    case  8: GPIOB->BRR = GPIO_PIN_2;   break;
    case  9: GPIOC->BRR = GPIO_PIN_8;   break;
    case 10: GPIOC->BRR = GPIO_PIN_6;   break;
    case 11: GPIOA->BRR = GPIO_PIN_8;   break;
    case 12: GPIOC->BRR = GPIO_PIN_10;  break;
    case 13: GPIOD->BRR = GPIO_PIN_2;   break;
    case 14: GPIOA->BRR = GPIO_PIN_10;  break;
    case 15: GPIOC->BRR = GPIO_PIN_12;  break;
    }
}


static uint8_t get_sense(void)
{
    uint16_t H = GPIOH->IDR;
    uint16_t C = GPIOC->IDR;

    return  ((H & GPIO_PIN_0 ) ? 0 : (1 << 0) ) |
            ((C & GPIO_PIN_2 ) ? 0 : (1 << 1) ) |
            ((C & GPIO_PIN_0 ) ? 0 : (1 << 2) ) |
            ((H & GPIO_PIN_1 ) ? 0 : (1 << 3) ) |
            ((C & GPIO_PIN_1 ) ? 0 : (1 << 4) ) |
            ((C & GPIO_PIN_15) ? 0 : (1 << 5) ) |
            ((C & GPIO_PIN_3 ) ? 0 : (1 << 6) ) |
            ((C & GPIO_PIN_13) ? 0 : (1 << 7) ) ;
}


int kb_scan_matrix(uint8_t *matrix)
{
    // scan drive lines: ~180 us
    //
    for (int i=0; i<16; i++) {
        discharge();
        set_drv(i);
        delay_us(3);
        matrix[i] = get_sense();
    }

    // ghost detection: ~10us
    //
    for (int i=0; i<15; i++) {
        if ((matrix[i] - 1) & matrix[i]) {
            // if >= 2 keys are pressed .. (bit bashing trick)
            //
            for (int j = i + 1; j<16; j++) {
                // .. check other rows for shared keys
                //
                if (matrix[i] & matrix[j])
                    return 0;
            }
        }
    }

    return 1;
}


int kb_get_fn_key(void)
{
    return !(GPIOC->IDR & GPIO_PIN_14);
}


int kb_get_power_key(void)
{
    return !(GPIOB->IDR & GPIO_PIN_9);
}


int kb_get_id(void)
{
    return
        (GPIOA->IDR & GPIO_PIN_9  ? 1 : 0) +
        (GPIOA->IDR & GPIO_PIN_15 ? 2 : 0) +
        (GPIOC->IDR & GPIO_PIN_11 ? 4 : 0);
}


void kb_set_brightness(uint8_t level)
{
    int pwm = gamma_tab[level];

    TIM2->CCR1  = pwm;  // PA0    LED_MIC
    TIM2->CCR2  = pwm;  // PA1    LED_POWER
    TIM21->CCR1 = pwm;  // PA2    LED_MUTE
    TIM21->CCR2 = pwm;  // PA3    LED_CAPS
    TIM22->CCR1 = pwm;  // PA6    LED_NUM
    TIM22->CCR2 = pwm;  // PA7    LED_SCROLL
    TIM2->CCR3  = pwm;  // PB10   LED_AUX
}


void kb_set_thinklight(uint8_t level)
{
    int pwm = gamma_tab[level];
    TIM2->CCR4  = pwm;  // PB11   LED_LIGHT
}


void kb_set_leds(const struct kb_out_report *report)
{
    if (report->_01_num_lock)
        TIM22->CCER |= TIM_CCER_CC1E;
    else
        TIM22->CCER &= ~TIM_CCER_CC1E;

    if (report->_02_caps_lock)
        TIM21->CCER |= TIM_CCER_CC2E;
    else
        TIM21->CCER &= ~TIM_CCER_CC2E;

    if (report->_03_scroll_lock)
        TIM22->CCER |= TIM_CCER_CC2E;
    else
        TIM22->CCER &= ~TIM_CCER_CC2E;
}
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

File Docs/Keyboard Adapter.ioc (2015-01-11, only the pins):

Mcu.UserName=STM32L052R8Tx
PA0-WKUP.Signal=S_TIM2_CH1
PA1.Signal=S_TIM2_CH2
PA11.Signal=USB_DM
PA12.Signal=USB_DP
PA13.Signal=SYS_SWDIO
PA14.Signal=SYS_SWCLK
PA2.Signal=S_TIM21_CH1
PA3.Signal=S_TIM21_CH2
PA6.Signal=S_TIM22_CH1
PA7.Signal=S_TIM22_CH2
PB10.Signal=S_TIM2_CH3
PB11.Signal=S_TIM2_CH4
PB6.Signal=USART1_TX
PB7.Signal=USART1_RX

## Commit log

2015-01-11 Initial import from a private repo
    [BOM.csv]
2015-01-28 Official USB PID 0x60c0 from OpenMoko. Thanks Harald!
2015-02-01 Added ThinkLight buttons: FN + PgUp increases brightness FN + PgDn decreases brightness
2017-04-30 3D Model for JAE-KX14-40-K2D receptacle
    [JAE-KX14-40-K2D.FCStd, JAE-KX14-40-K2D.stp]
2017-04-30 3D Model for JAE-AA01B-S040VA1 receptacle
    [JAE-AA01B-S040VA1.ipt, JAE-AA01B-S040VA1.stp]
2017-04-30 first layout version
    [nucular-keyboard.kicad_pcb, nucular-keyboard.sch]
2017-05-01 more footprint and library stuff
    [Molex_105017-0001_USB-Micro-B.step, nucular-keyboard.sch]
2017-05-02 Corrected footprint
    [nucular-keyboard.kicad_pcb]
2017-05-02 Big clean-up
    [Molex_105017-0001_USB-Micro-B.step, nucular-keyboard.kicad_pcb, nucular-keyboard.sch]
2017-05-03 Renamed libray to 000-xxx, so it's always on top
    [nucular-keyboard.kicad_pcb, nucular-keyboard.sch]
2017-05-07 fill polys
    [nucular-keyboard.kicad_pcb, nucular-keyboard.sch]
2017-05-19 plane layers
    [nucular-keyboard.kicad_pcb, nucular-keyboard.sch]

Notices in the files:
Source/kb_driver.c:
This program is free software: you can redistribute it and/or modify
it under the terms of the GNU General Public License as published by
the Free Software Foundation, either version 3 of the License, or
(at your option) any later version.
